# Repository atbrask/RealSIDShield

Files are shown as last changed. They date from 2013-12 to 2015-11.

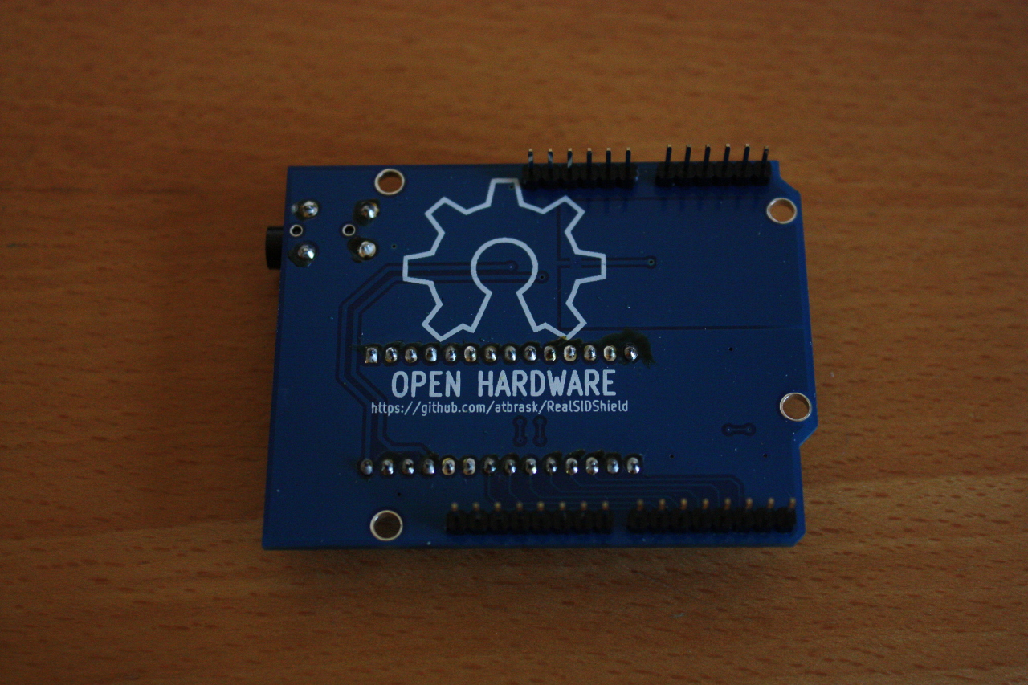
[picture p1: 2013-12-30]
Pictures/Finished board bottom.JPG

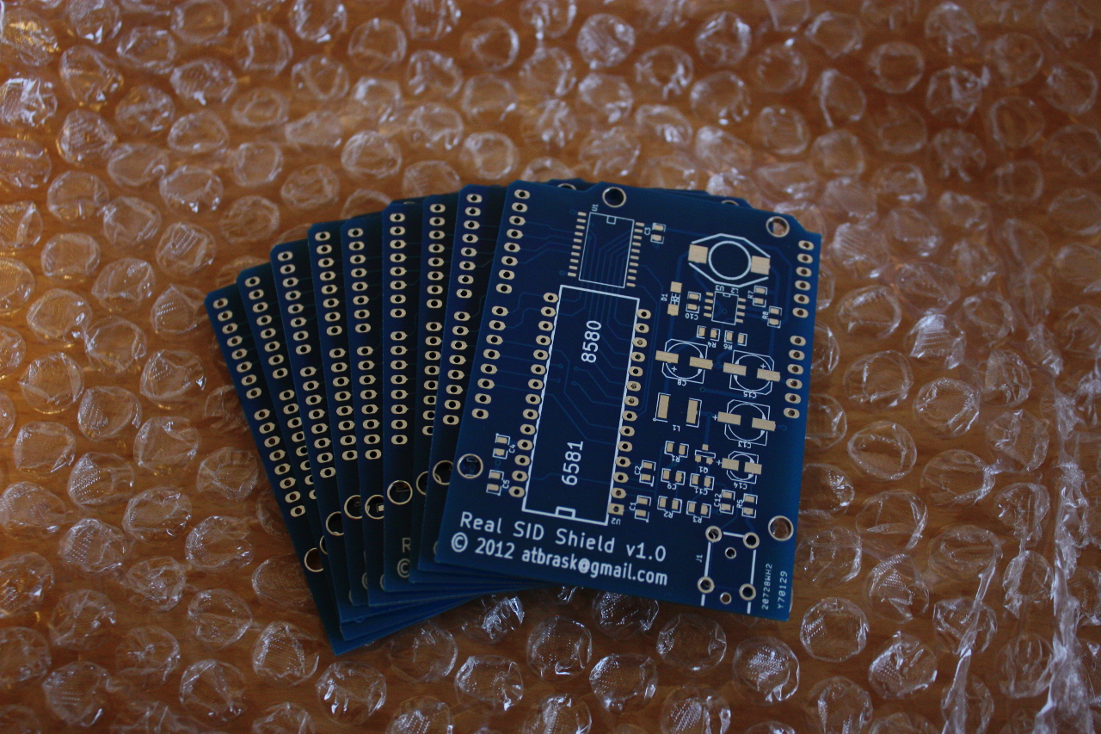
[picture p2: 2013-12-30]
Pictures/PCBs.JPG

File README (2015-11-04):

RealSIDShield
Version 1.0

Copyright (c) 2012,2013, A.T.Brask (atbrask[at]gmail[dot]com)

This is an Arduino shield that makes it easy to use a MOS Technology 6581/8580 SID chip (the famous C64 sound chip). This repository contains all necessary PCB design files as well as some photos and a bit of demonstration code. At some point I'll write a post about it on my blog at http://www.atbrask.dk/ with some further explanations and perhaps some audio/video examples.

The design works without any big problems. There are a couple of minor issues, but I think it's good enough to release into the wild. The board basically provides the necessary support electronics for the SID chip to work and be accessible from the Arduino. So far, I have only tested it with a 8580, but it should work fine with a 6581 too. The biggest difference is the VDD voltage for the SID chip. The board includes a little step-up converter for this. Once a board is built, it can only be used with one of the two kinds of SID.

The example code is a simple music player that plays .SID files. It consists of a Python script that emulates the Commodore 64 CPU (using the py65 package from PyPI) and an Arduino sketch that handles the SID chip.

I did have a few left over PCBs for sale, but as of October 2015 I'm all out. If anyone is interested, they can pretty easily order new ones themselves from a PCB house using the gerber files in this repository. If any specific components are unavailable/EOL you can just swap them for similar ones. Only a few of the capacitors and resistors are more or less critical.

---------------
IMPORTANT NOTES
---------------

The Arduino sketch code has only been tested on an Arduino Uno. The code uses direct port access for I/O and depends on the specific mapping from the B and D ports on an ATmega168/328 to the digital pins on the Arduino board. This makes the code incompatible with Arduino boards with different port/pin mappings. One such case is the Arduino Leonardo which is currently not (yet) supported.

!!! BUILD AT YOUR OWN RISK !!!
If you end up frying your SID chip (or any other equipment), it's not my problem. :-)

Some of the component values depend on the model of SID you plan to use with the shield. This is very important to get right. Plugging a 8580 into a 6581 board may damage the chip. The other way around is probably less damaging, but it would simply not yield any sound. Please use an IC socket for the SID chip. It hurts to see it get soldered in place... :-)

If you build this board, please check that the correct voltage is present on the SID chip's pin 28 (VDD) before you plug in the chip. It should read 9V for a 8580 board and 12V for a 6581 board.

6581-specific component values:
C1 : 470pF
C2 : 470pF
R1 : 1K
R4 : 13K
R6 : 1K5
U2 : MOS 6581 :-)

8580-specific component values:
C1 : 22nF
C2 : 22nF
R1 : Not connected
R4 : 6K2
R6 : 1K
U2 : MOS 8580 :-)

The rest of the component values can be found in the KiCAD project files.

------------
KNOWN ISSUES
------------

1) There are no C6 or C7. These were added for the analog paddle inputs, but this feature was scrapped.

2) The design specifies 560pF for C10. However, this yielded a too-low switching frequency in the step-up converter. As far as I remember, I switched this with a 220pF. The step-up converter is still noisy, but at least it doesn't have a very annoying audible tone.

3) The output stage was copied verbatim from an old C128 schematic. However, it seems to have a large gain, which makes the output very loud.

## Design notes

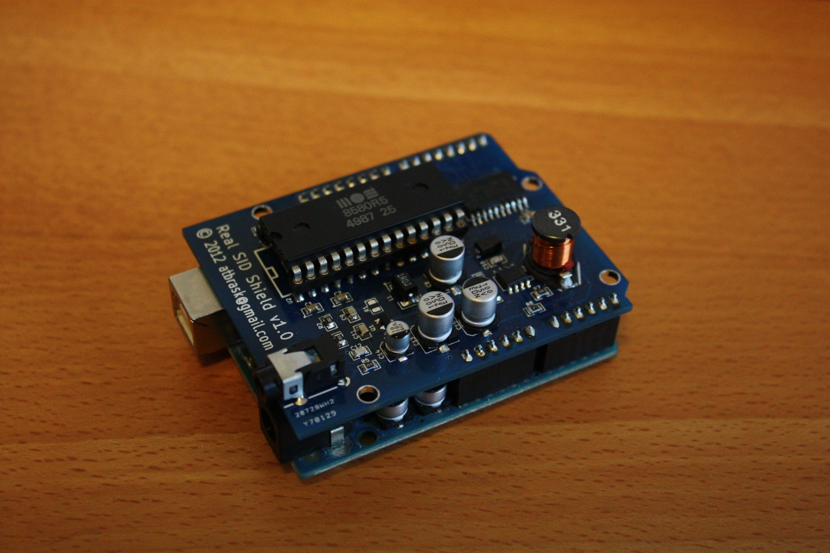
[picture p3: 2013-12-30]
Pictures/Finished board mounted.JPG

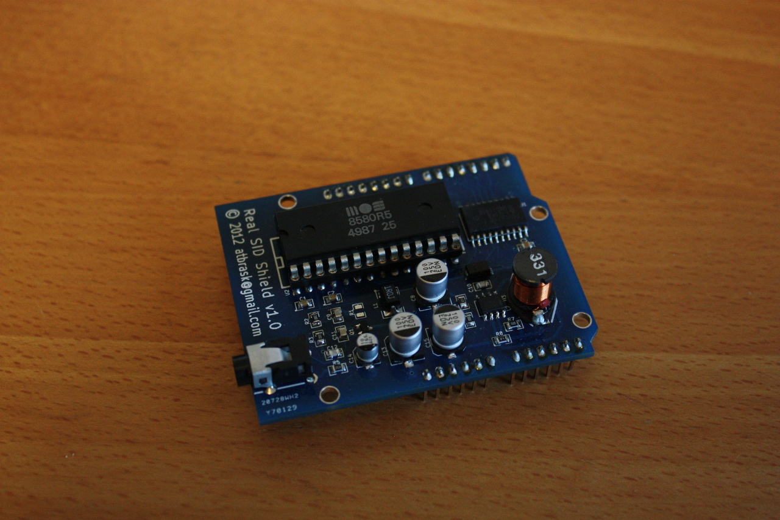
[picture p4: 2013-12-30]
Pictures/Finished board top.JPG

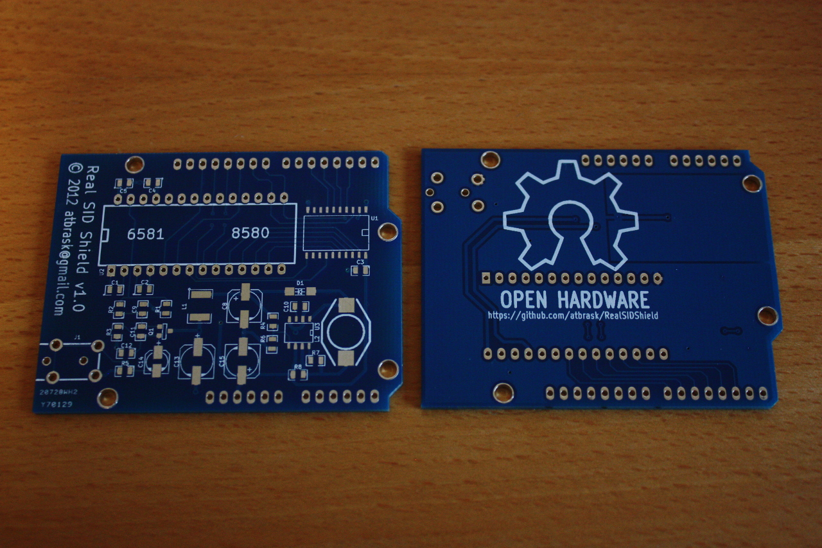
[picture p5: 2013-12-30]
Pictures/PCB top bottom.JPG

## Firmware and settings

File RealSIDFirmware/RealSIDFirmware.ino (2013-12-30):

/*
RealSIDFirmware
Version 1.0

Copyright (c) 2013, A.T.Brask (atbrask[at]gmail[dot]com)
All rights reserved,

Demonstration code for the RealSIDShield Arduino shield.

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
1. Redistributions of source code must retain the above copyright notice, this
   list of conditions and the following disclaimer. 
2. Redistributions in binary form must reproduce the above copyright notice,
   this list of conditions and the following disclaimer in the documentation
   and/or other materials provided with the distribution. 

THIS SOFTWARE IS PROVIDED BY THE COPYRIGHT HOLDERS AND CONTRIBUTORS "AS IS" AND
ANY EXPRESS OR IMPLIED WARRANTIES, INCLUDING, BUT NOT LIMITED TO, THE IMPLIED
WARRANTIES OF MERCHANTABILITY AND FITNESS FOR A PARTICULAR PURPOSE ARE
DISCLAIMED. IN NO EVENT SHALL THE COPYRIGHT OWNER OR CONTRIBUTORS BE LIABLE FOR
ANY DIRECT, INDIRECT, INCIDENTAL, SPECIAL, EXEMPLARY, OR CONSEQUENTIAL DAMAGES
(INCLUDING, BUT NOT LIMITED TO, PROCUREMENT OF SUBSTITUTE GOODS OR SERVICES;
LOSS OF USE, DATA, OR PROFITS; OR BUSINESS INTERRUPTION) HOWEVER CAUSED AND
ON ANY THEORY OF LIABILITY, WHETHER IN CONTRACT, STRICT LIABILITY, OR TORT
(INCLUDING NEGLIGENCE OR OTHERWISE) ARISING IN ANY WAY OUT OF THE USE OF THIS
SOFTWARE, EVEN IF ADVISED OF THE POSSIBILITY OF SUCH DAMAGE.
*/

#include "SID.h"

char newsid[25];
char oldsid[25];
bool dataready = false;
char buffer[50];
int idx = 0;
unsigned long lastupdate = 0;
SID SIDchip;

void setup()
{
  Serial.begin(115200);
  SIDchip.Reset();
}

char decode(char ch)
{
  if (ch >= 'A')
    return ch - 55;
  else
    return ch - 48;
}

void updateSID()
{
  for (int i = 0; i < 25; i++)
  {
    if (oldsid[i] != newsid[i])
    {
      oldsid[i] = newsid[i];
      SIDchip.Poke(i, newsid[i]);
    }
  }
}

void readData()
{
  if (Serial.available() > 0)
  {
      char ch = Serial.read();
      if (ch == '!')
      {
        if (idx == 50)
        {
          for (int i = 0; i < 25; i++)
          {
            char highnibble = buffer[i * 2];
            char lownibble = buffer[i * 2 + 1];
            newsid[i] = (decode(highnibble) << 4) | decode(lownibble);
          }
          dataready = true;
        }
        idx = 0;
      }
      else
      {
        if (idx < 50)
          buffer[idx] = ch;
        idx++;
      }
  }
}

void loop()
{
  if (!dataready)
    readData();
  
  // Check time and update SID if needed
  unsigned long timenow = millis();
  if (timenow - lastupdate >= 20)
  {
    lastupdate = timenow;
    if (dataready == true)
    {
      dataready = false;
      updateSID();
    }
  
    // Send more data!
    Serial.write('?');
    Serial.flush();
  }
}

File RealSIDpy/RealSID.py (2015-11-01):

#!/usr/bin/env python
'''
RealSID.py
Version 1.0

Copyright (c) 2013, A.T.Brask (atbrask[at]gmail[dot]com)
All rights reserved,

Very rudimentary SID player for demonstrating the RealSIDShield Arduino shield.
Basically, it emulates a 6502 CPU with 64KB of memory. No VIC or CIA chips.
It works by running the play routine at ~50 Hz. After each run, it updates the
registers in real SID chip connected via the Arduino.

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
1. Redistributions of source code must retain the above copyright notice, this
   list of conditions and the following disclaimer. 
2. Redistributions in binary form must reproduce the above copyright notice,
   this list of conditions and the following disclaimer in the documentation
   and/or other materials provided with the distribution. 

THIS SOFTWARE IS PROVIDED BY THE COPYRIGHT HOLDERS AND CONTRIBUTORS "AS IS" AND
ANY EXPRESS OR IMPLIED WARRANTIES, INCLUDING, BUT NOT LIMITED TO, THE IMPLIED
WARRANTIES OF MERCHANTABILITY AND FITNESS FOR A PARTICULAR PURPOSE ARE
DISCLAIMED. IN NO EVENT SHALL THE COPYRIGHT OWNER OR CONTRIBUTORS BE LIABLE FOR
ANY DIRECT, INDIRECT, INCIDENTAL, SPECIAL, EXEMPLARY, OR CONSEQUENTIAL DAMAGES
(INCLUDING, BUT NOT LIMITED TO, PROCUREMENT OF SUBSTITUTE GOODS OR SERVICES;
LOSS OF USE, DATA, OR PROFITS; OR BUSINESS INTERRUPTION) HOWEVER CAUSED AND
ON ANY THEORY OF LIABILITY, WHETHER IN CONTRACT, STRICT LIABILITY, OR TORT
(INCLUDING NEGLIGENCE OR OTHERWISE) ARISING IN ANY WAY OUT OF THE USE OF THIS
SOFTWARE, EVEN IF ADVISED OF THE POSSIBILITY OF SUCH DAMAGE.
'''

import time
import serial
import argparse
from py65.devices import mpu6502

def getSIDstate(memory):
    return ''.join(["{0:02X}".format(byte) for byte in memory[0xD400:0xD419]])

def runCPU(cpu, newpc, newa, newx, newy):
    cpu.pc = newpc
    cpu.a = newa
    cpu.x = newx
    cpu.y = newy
    cpu.sp = 0xFF 
    running = True
    instructioncount = 0
    while running and instructioncount < 1000000:
        ## Test for return instructions RTI (0x40) and RTS (0x60)
        if cpu.ByteAt(cpu.pc) in (0x40, 0x60) and cpu.sp == 0xFF:
            running = False
        
        ## Test for BRK (0x00)
        if cpu.ByteAt(cpu.pc) == 0x00:
            running = False
        
        ## Step one instruction
        cpu.step()
        instructioncount += 1

        ## Test for jump into Kernal interrupt handler exit
        if (cpu.ByteAt(0x01) & 0x07) != 0x5 and cpu.pc in (0xea31, 0xea81):
            running = False

def playsid(filename, subtune, playseconds, serialport, baudrate):
    ## Parse file header
    data = [ord(byte) for byte in open(filename, 'rb').read()]

    filetype = ''.join([chr(ch) for ch in data[0:4]])
    version = data[5]
    print "SID type: {0} (version {1})".format(filetype, version)
    if filetype == "RSID":
        print "Warning: RSID files may not play properly. YMMV."

    dataoffset = (data[6] << 8) | data[7] 

    loadaddress = (data[8] << 8) | data[9]
    print "Load address: {0:04X}".format(loadaddress)

    initaddress = (data[10] << 8) | data[11]
    print "Init address: {0:04X}".format(initaddress)

    playaddress = (data[12] << 8) | data[13]
    print "Play address: {0:04X}".format(playaddress)

    songs = (data[14] << 8) | data[15]
    defaultsong = (data[16] << 8) | data[17]
    print "Found {0} song(s) (default song is {1})".format(songs, defaultsong)
    if subtune == -1 or subtune > songs:
        subtune = defaultsong

    speed = (data[18] << 24) | (data[19] << 16) | (data[20] << 8) | data[21]
    if speed == 0:
        print "Using 50Hz vertical blank interrupt."
    else:
        print "Warning: Some songs require the CIA 1 timer (not implemented)."

    title = ''.join([chr(ch) for ch in data[22:54]])
    author = ''.join([chr(ch) for ch in data[54:86]])
    released = ''.join([chr(ch) for ch in data[86:118]])

    print "Title    : {0}".format(title)
    print "Author   : {0}".format(author)
    print "Released : {0}".format(released)

    ## Check load address
    if loadaddress == 0:
        print "Warning: SID has load address 0, reading from C64 binary data"
        loadaddress = data[dataoffset] | (data[dataoffset + 1] << 8)
        dataoffset += 2
        print "New load address is {0:04X}".format(loadaddress)

    ## Check init address
    if initaddress == 0:
        print "Warning: SID has init address 0, cloning load address instead"
        initaddress = loadaddress
        print "New init address is {0:04X}".format(initaddress)

    ## Setup memory
    memory = [0] * 0x10000
    memory[0x01] = 0x37;
    for idx, byte in enumerate(data[dataoffset:]):
        memory[loadaddress + idx] = byte

    ## Setup CPU
    cpu = mpu6502.MPU(memory)

    ## Init SID tune
    print "Initializing song {0}...".format(subtune)
    runCPU(cpu, initaddress, subtune - 1, 0, 0)

    ## Check play address
    if playaddress == 0:
        print "Warning: SID has play address 0, reading from interrupt vector"
        if (memory[0x01] & 0x07) == 0x5:
            playaddress = memory[0xfffe] | (memory[0xffff] << 8)
        else:
            playaddress = memory[0x314] | (memory[0x315] << 8)
        print "New play address is {0:04X}".format(playaddress)

    ## Init RealSIDShield and wait for it to reset properly
    print "Using serial port {0} at {1} baud...".format(serialport, baudrate)
    print "Initializing serial connection to the Arduino..."
    ser = serial.Serial(port = serialport,
                        baudrate = baudrate,
                        timeout = 1)
    time.sleep(0.1)
    ser.flushInput()

    ## Play SID tune!
    if playseconds == -1:
        print "Playing..."
    else:
        print "Playing for {0} seconds...".format(playseconds)
    frames = 0
    while(playseconds == -1 or frames < playseconds * 50):
        if ser.read() == '?':
            runCPU(cpu, playaddress, 0, 0, 0)
            ser.write(getSIDstate(memory) + "!")
            ser.flush()
            frames += 1
        else:
            print "I/O error..."

    ser.flush()
    ser.close()

if __name__ == "__main__":
    parser = argparse.ArgumentParser(description="RealSID.py v1.0 - A very rudimentary SID player for the RealSIDShield (c) 2013 atbrask")
    
    parser.add_argument("serialport", help="The serial port the Arduino is connected to")
    parser.add_argument("filename", help="Input SID file")
    parser.add_argument("-s", "--song", type=int, default=-1, help="The song number to be played (default is specified in the SID file)")
    parser.add_argument("-t", "--time", type=int, default=-1, help="The desired playtime in seconds (default is forever)")
    parser.add_argument("-b", "--baudrate", type=int, default=115200, help="Specify baudrate (default is 115200)")

    args = parser.parse_args()

    playsid(args.filename, args.song, args.time, args.serialport, args.baudrate)

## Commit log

2013-12-30 First complete commit
    [RealSIDShield.brd, RealSIDShield.sch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]
2015-10-21 Updated README (I'm all out of extra PCBs)
2015-11-01 Fixed SID loading on Windows
    [RealSID.py]
